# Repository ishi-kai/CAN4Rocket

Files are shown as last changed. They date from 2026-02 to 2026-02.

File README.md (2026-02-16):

# CAN Base Board for Rocket
CAN Base Board for Rocket.
The power supply section and the CAN communication section are insulated.

## Base System
This is a version with a universal board attached to the CAN base board.  
- [CAN_Isolation](./CAN_Isolation/)
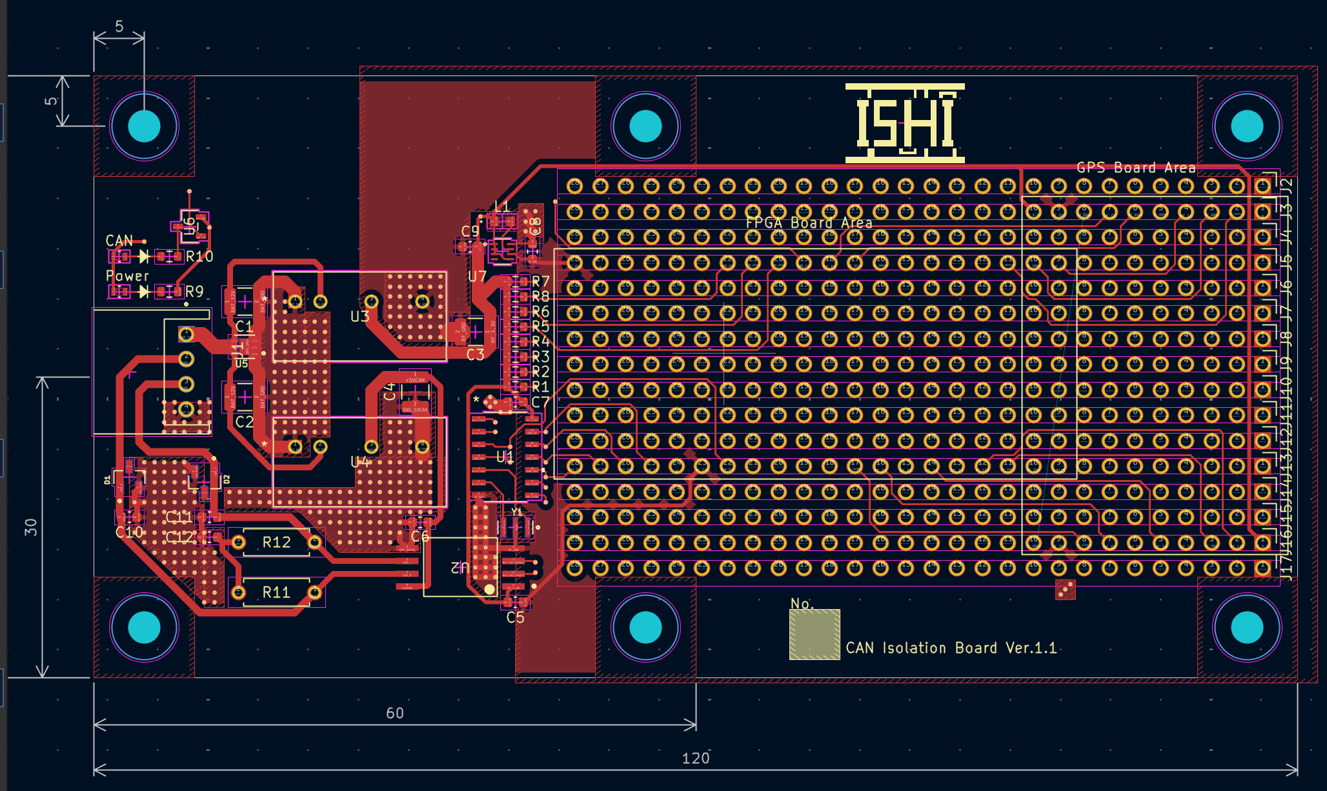
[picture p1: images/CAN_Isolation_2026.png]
CAN_Isolation
- 

## Mini System
This is a mini version of the baseboard.  

- [CAN_Isolation_mini](./CAN_Isolation_mini/)
- [CAN_Isolation_mini_3.3V](./CAN_Isolation_mini_3.3V/)
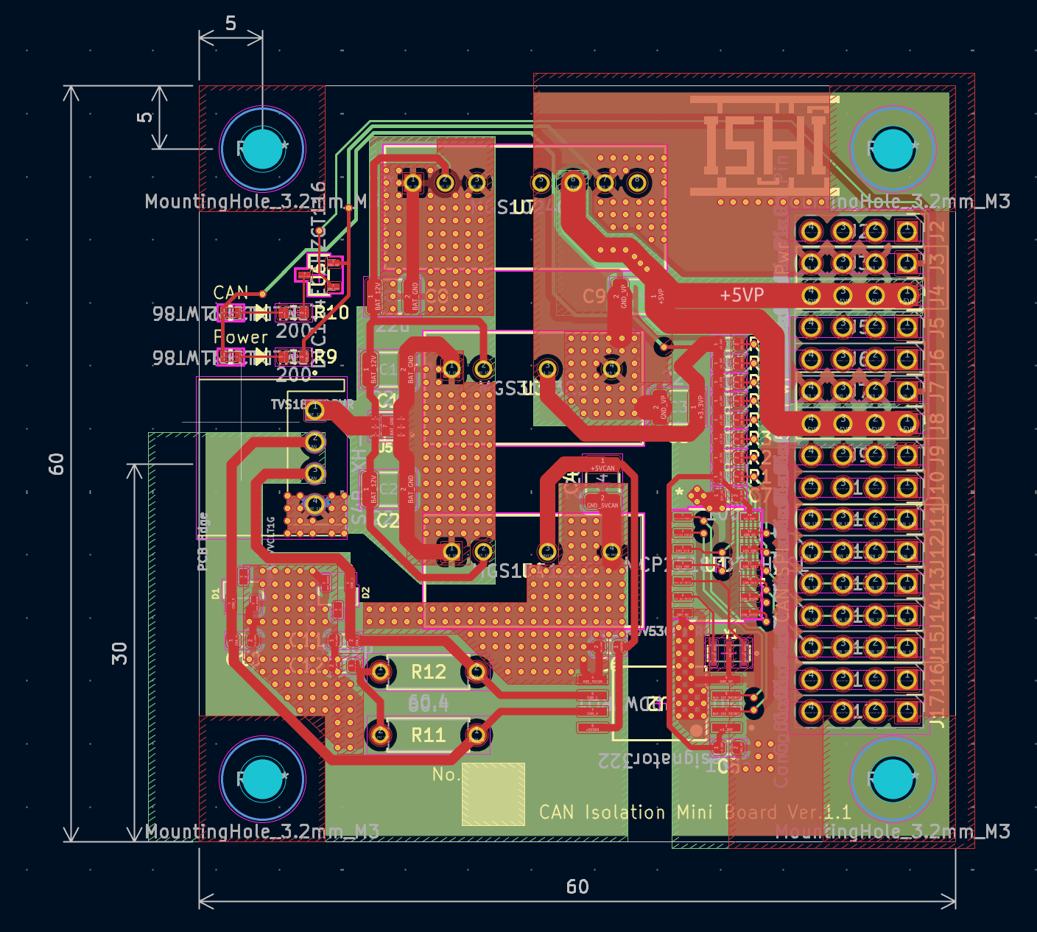
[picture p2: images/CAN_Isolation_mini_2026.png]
CAN_Isolation_mini
- 

## High-Current Board for Servos System
This is a board with an XT60 connector for servos added to the mini version.  

- [CAN_Isolation_mini_XT60](./CAN_Isolation_mini_XT60/)
- [CAN_Isolation_mini_XT60_3.3V](./CAN_Isolation_mini_XT60_3.3V/)
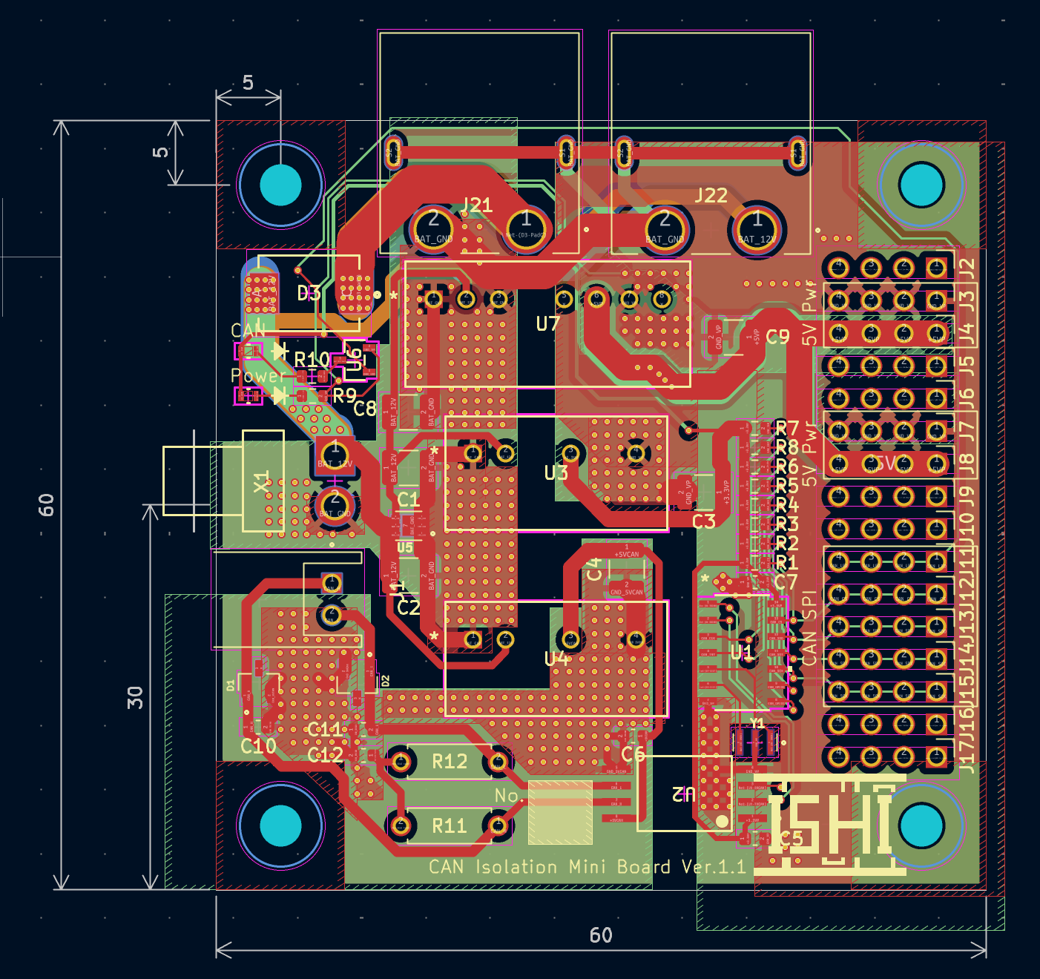
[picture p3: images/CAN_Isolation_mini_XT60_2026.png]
CAN_Isolation_mini_XT60
-

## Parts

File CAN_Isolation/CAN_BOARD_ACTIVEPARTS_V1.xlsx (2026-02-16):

出荷時に原産国が変わる場合があります。
表示されているHTSUSおよびECCN情報は情報提供のみを目的としたもので、分類の正確性や信頼性を表明または保証するものではありません。すべての情報は「現状のまま」提供されており、予告なしに変更される場合があります。提供された情報の使用は、Digi-Keyに頼ることなく、ユーザーの責任において使用されるものとします。
インデックス | メーカー品番 | メーカー名 | 商品概要 | リードタイム | 入手性 | 在庫状況 | 仕損率 | リクエスト数量1 | パック数量1 | パックタイプ1 | Digi-Key品番1 | 単価1 | 金額1 | 最小発注数量1 | 客先参照品番 | リクエスト品番 | リードタイム（週） | データシート | 参照名 | 米国輸入関税 | メモ | 部品状況 | RoHSステータス | 湿度感度レベル（MSL） | ECCN | HTSUS | 原産国 | 環境規制対応 | オリジナル品番 | 画像 | 製品に関する注意事項
1 | MCP2518FDT-H/SL | Microchip Technology | IC CAN CONTROLLER SPI 14SOIC |  | 4,201 | 在庫品目 |  | 1 | 1 | Cut Tape (CT) | MCP2518FDT-H/SLCT-ND | 2.03000 | $2.03 | 1 | 1 | MCP2518FDT-H/SLCT-ND | 6 | https://ww1.microchip.com/downloads/en/DeviceDoc/External-CAN-FD-Controller-with-SPI-Interface-DS20006027B.pdf |  | N/A |  | アクティブ | ROHS3対応 | 3（168時間） | EAR99 | 8542.39.0070 | Thailand | https://ww1.microchip.com/downloads/aemDocuments/documents/corporate-responsibilty/environmental/product-regulatory-information/Semiconductor_EnvCoC.pdf|https://ww1.microchip.com/downloads/aemDocuments/documents/corporate-responsibilty/environmental/product-regulatory-information/Microchip_REACH_Statement.pdf | MCP2518FDT-H/SLCT-ND | https://mm.digikey.com/Volume0/opasdata/d220001/medias/images/4283/150%7EC04-065%7EOD%2C-SL%7E14.jpg
2 | ISO1042QDWVRQ1 | Texas Instruments | IC TRANSCEIVER FULL 1/1 8SOIC |  | 2,190 | 在庫品目 |  | 1 | 1 | Cut Tape (CT) | 296-ISO1042QDWVRQ1CT-ND | 5.20000 | $5.20 | 1 | 1 | 296-ISO1042QDWVRQ1CT-ND | 12 | https://www.ti.com/general/docs/suppproductinfo.tsp?distId=10 |  | N/A |  | アクティブ | ROHS3対応 | 3（168時間） | EAR99 | 8542.39.0060 | Taiwan |  | 296-ISO1042QDWVRQ1CT-ND | https://mm.digikey.com/Volume0/opasdata/d220001/derivates/6/001/202/821/296%7E4218796%7EDWV%7E8_web%28640x640%29.jpg
3 | CSTNE20M0V530000R0 | Murata Electronics | CERAMIC RES 20.0000MHZ 15PF SMD |  | 15,730 | 在庫品目 |  | 1 | 1 | Cut Tape (CT) | 490-17953-1-ND | 0.22000 | $0.22 | 1 | 1 | 490-17953-1-ND | 16 | https://www.murata.com/en/products/productdata/8801161510942/SPEC-CSTNE20M0V530000R0.pdf |  | N/A |  | アクティブ | ROHS3対応 | 1（無制限） | EAR99 | 8548.00.0000 | Japan |  | 490-17953-1-ND | https://mm.digikey.com/Volume0/opasdata/d220001/medias/images/2407/CSTCR-G%20SERIES.jpg
4 | TPS610333QDRLRQ1 | Texas Instruments | IC REG BOOST 5V SOT583 |  | 2,781 | 在庫品目 |  | 1 | 1 | Cut Tape (CT) | 296-TPS610333QDRLRQ1CT-ND | 1.75000 | $1.75 | 1 | 1 | 296-TPS610333QDRLRQ1CT-ND | 12 | https://www.ti.com/lit/ds/symlink/tps610333-q1.pdf?ts=1704486161808 |  | N/A |  | アクティブ | ROHS3対応 | 1（無制限） | EAR99 | 8542.39.0090 | Philippines |  | 296-TPS610333QDRLRQ1CT-ND | https://mm.digikey.com/Volume0/opasdata/d220001/medias/images/6168/296%7E4224486%7EDRL%7E8.jpg
5 | DTC114ECAHZGT116 | Rohm Semiconductor | TRANS PREBIAS NPN 0.1A SST3 |  | 2,933 | 在庫品目 |  | 1 | 1 | Cut Tape (CT) | DTC114ECAHZGT116CT-ND | 0.17000 | $0.17 | 1 | 1 | DTC114ECAHZGT116CT-ND | 18 | https://www.rohm.co.jp/datasheet?p=DTC114ECAHZG&dist=Digi-key&media=referral&campaign=Digi-key |  | N/A |  | アクティブ | ROHS3対応 | 1（無制限） | EAR99 | 8541.21.0075 | South Korea | https://fscdn.rohm.com/en/techdata_basic/transistor/anti_whisker/TR_Whisker-e.pdf|https://fscdn.rohm.com/en/techdata_basic/transistor/esd/ESD_TR-DTC114ECAHZG-e.pdf|https://fscdn.rohm.com/en/techdata_basic/transistor/msl/TR_MSL-e.pdf | DTC114ECAHZGT116CT-ND | https://mm.digikey.com/Volume0/opasdata/d220001/medias/images/6347/846%7ESST3%7ESST%7E3.jpg
6 | MGS3123R3 | コーセル | DC DC CONVERTER 3.3V |  | 1 | 在庫品目 |  | 1 | 1 | Box | 1776-1088-ND | 14.99000 | $14.99 | 1 | 1 | 1776-1088-ND | 13 | https://en.cosel.co.jp/tool/tag/pdf/SFE_MG1R5-10.pdf |  | N/A |  | アクティブ | ROHS3対応 | 適用外 | EAR99 | 8504.40.9580 | Japan | https://en.cosel.co.jp/contact/chemical/rohs_dl/pdf/e_syoumeisyo_10.pdf | 1776-1088-ND | https://mm.digikey.com/Volume0/opasdata/d220001/medias/images/2173/MFG_MGS3.jpg
7 | MGS1R51205 | コーセル | DC DC CONVERTER 5V |  | 5 | 在庫品目 |  | 1 | 1 | Box | 1776-1077-ND | 11.43000 | $11.43 | 1 | 1 | 1776-1077-ND | 13 | https://en.cosel.co.jp/tool/tag/pdf/SFE_MG1R5-10.pdf |  | N/A |  | アクティブ | ROHS3対応 | 適用外 | EAR99 | 8504.40.9580 | Japan | https://en.cosel.co.jp/contact/chemical/rohs_dl/pdf/e_syoumeisyo_10.pdf | 1776-1077-ND | https://mm.digikey.com/Volume0/opasdata/d220001/medias/images/2320/MFG_MGS1R5.jpg
8 | MMBZ27VCLT1G | onsemi | TVS DIODE 22VWM 38VC SOT233 |  | 21,010 | 在庫品目 |  | 2 | 2 | Cut Tape (CT) | MMBZ27VCLT1GOSCT-ND | 0.12000 | $0.24 | 1 |  | MMBZ27VCLT1GOSCT-ND | 8 | https://www.onsemi.com/pdf/datasheet/mmbz15vdlt1-d.pdf |  | N/A |  | アクティブ | ROHS3対応 | 1（無制限） | EAR99 | 8541.10.0080 | China | https://www.onsemi.com/site/pdf/RoHS-statement.pdf|https://www.onsemi.com/site/pdf/REACH-compliance-statement.pdf|https://www.onsemi.com/PowerSolutions/MaterialComposition.do?export=pdf&opnId=MMBZ27VCLT1G | MMBZ27VCLT1GOSCT-ND | https://mm.digikey.com/Volume0/opasdata/d220001/medias/images/4846/488_SOT-23-3%2CTO-236-3%2CMicro3%2CSSD3%2CSST3.jpg
9 | TVS1800DRVR | Texas Instruments | UNIDIR PRECISION SURGE DIODE |  | 2,563 | 在庫品目 |  | 1 | 1 | Cut Tape (CT) | 296-52186-1-ND | 0.50000 | $0.50 | 1 |  | 296-52186-1-ND | 6 | https://www.ti.com/general/docs/suppproductinfo.tsp?distId=10 |  | N/A |  | アクティブ | ROHS3対応 | 1（無制限） | EAR99 | 8542.39.0060 | China |  | 296-52186-1-ND | https://mm.digikey.com/Volume0/opasdata/d220001/medias/images/317/296%7E4222173%7EDRV%7E6.jpg

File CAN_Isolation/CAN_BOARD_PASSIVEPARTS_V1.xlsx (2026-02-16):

出荷時に原産国が変わる場合があります。
表示されているHTSUSおよびECCN情報は情報提供のみを目的としたもので、分類の正確性や信頼性を表明または保証するものではありません。すべての情報は「現状のまま」提供されており、予告なしに変更される場合があります。提供された情報の使用は、Digi-Keyに頼ることなく、ユーザーの責任において使用されるものとします。
インデックス | メーカー品番 | メーカー名 | 商品概要 | リードタイム | 入手性 | 在庫状況 | 仕損率 | リクエスト数量1 | パック数量1 | パックタイプ1 | Digi-Key品番1 | 単価1 | 金額1 | 最小発注数量1 | 客先参照品番 | リクエスト品番 | リードタイム（週） | データシート | 参照名 | 米国輸入関税 | メモ | 部品状況 | RoHSステータス | 湿度感度レベル（MSL） | ECCN | HTSUS | 原産国 | 環境規制対応 | オリジナル品番 | 画像 | 製品に関する注意事項
1 | GCM32EC71E226KE36K | Murata Electronics | CAP CER 22UF 25V X7S 1210 |  | 30,191 | 在庫品目 |  | 4 | 4 | Cut Tape (CT) | 490-GCM32EC71E226KE36KCT-ND | 197.00000 | ¥788 | 1 | 4 | 490-GCM32EC71E226KE36KCT-ND | 14 |  |  | N/A |  | アクティブ | ROHS3対応 | 1（無制限） | EAR99 | 8532.24.0020 | Japan |  | 490-GCM32EC71E226KE36KCT-ND | https://mm.digikey.com/Volume0/opasdata/d220001/medias/images/5447/490-Ceramic-Capacitor-Tan-Field.jpg
2 | 0603YC104J4T4A | KYOCERA AVX | CAP CER 0.1UF 16V X7R 0603 |  | 19,142 | 在庫品目 |  | 3 | 3 | Cut Tape (CT) | 478-KAM15AR71C104JMCT-ND | 52.00000 | ¥156 | 1 | 5 | 478-KAM15AR71C104JMCT-ND | 12 | https://datasheets.kyocera-avx.com/AutoMLCC.pdf |  | N/A |  | アクティブ | ROHS3対応 | 1（無制限） | EAR99 | 8532.24.0020 | El Salvador |  | 478-KAM15AR71C104JMCT-ND | https://mm.digikey.com/Volume0/opasdata/d220001/medias/images/4845/478_0603-%281608-Metric%29-0%2C90mm.jpg
3 | LCCNF1608KKTR47MA | Taiyo Yuden | INDUCTOR MULTILAYER 0.47UH 0603 |  | 5,312 | 在庫品目 |  | 1 | 1 | Cut Tape (CT) | 587-LCCNF1608KKTR47MACT-ND | 69.00000 | ¥69 | 1 | 1 | 587-LCCNF1608KKTR47MACT-ND | 7 | https://mm.digikey.com/Volume0/opasdata/d220001/medias/docus/5056/LCCNF1608KKTR47MA_Spec.pdf |  | N/A |  | アクティブ | ROHS3対応 | 1（無制限） | EAR99 | 8504.50.8000 | Japan |  | 587-LCCNF1608KKTR47MACT-ND | https://mm.digikey.com/Volume0/opasdata/d220001/derivates/6/001/157/742/MFG_LCCNFxxxxKKTxxxMA_web%28640x640%29.jpg
4 | ERJ-PA3F1002V | Panasonic Electronic Components | RES SMD 10K OHM 1% 1/3W 0603 |  | 90,888 | 在庫品目 |  | 8 | 8 | Cut Tape (CT) | P10KBYCT-ND | 22.00000 | ¥176 | 1 | 8 | P10KBYCT-ND | 12 | https://industrial.panasonic.com/cdbs/www-data/pdf/RDO0000/AOA0000C331.pdf |  | N/A |  | アクティブ | ROHS3対応 | 1（無制限） | EAR99 | 8533.21.0030 | Japan | https://industrial.panasonic.com/cdbs/www-cgi/auto-publishing.cgi?type=ROSU&region=WW&layer=4&cd=AOA0002 | P10KBYCT-ND | https://mm.digikey.com/Volume0/opasdata/d220001/medias/images/4322/cut-tape-render.jpg
5 | ERJ-3GEYJ201V | Panasonic Electronic Components | RES SMD 200 OHM 5% 1/10W 0603 |  | 394,282 | 在庫品目 |  | 2 | 2 | Cut Tape (CT) | P200GCT-ND | 16.00000 | ¥32 | 1 | 2 | P200GCT-ND | 12 | https://industrial.panasonic.com/cdbs/www-data/pdf/RDA0000/AOA0000C301.pdf |  | N/A |  | アクティブ | ROHS3対応 | 1（無制限） | EAR99 | 8533.21.0030 | China | https://industrial.panasonic.com/cdbs/www-cgi/auto-publishing.cgi?type=ROSU&region=WW&layer=4&cd=AOA0002 | P200GCT-ND | https://mm.digikey.com/Volume0/opasdata/d220001/medias/images/2606/MFG_ERJ-P6W%20Series.jpg
6 | SMLD12EN1WT86C | Rohm Semiconductor | LONG LIFE TYPE MINI-MOLD CHIP LE |  | 548 | 在庫品目 |  | 2 | 2 | Cut Tape (CT) | 846-SMLD12EN1WT86CCT-ND | 88.00000 | ¥176 | 1 | 2 | 846-SMLD12EN1WT86CCT-ND | 10 | https://www.rohm.com/datasheet?p=SMLD12EN1W(C)&dist=Digi-Key&media=referral&campaign=Digi-Key |  | N/A |  | アクティブ | ROHS3対応 | 3（168時間） | EAR99 | 8541.41.0000 | China |  | 846-SMLD12EN1WT86CCT-ND | https://mm.digikey.com/Volume0/opasdata/d220001/medias/images/5739/MFG_SMLD12EN1WT86C.jpg
7 | CHV0603N250470GCT | Cal-Chip Electronics, Inc. | HVCAP0603 COG 47PF 2% 250V |  | 2,968 | 在庫品目 |  | 2 | 2 | Cut Tape (CT) | 4713-CHV0603N250470GCT-ND | 84.00000 | ¥168 | 1 |  | 4713-CHV0603N250470GCT-ND | 8 | https://calchip.com/wp-content/uploads/2023/02/chv_series.pdf |  | N/A |  | アクティブ | ROHS3対応 | 1（無制限） | EAR99 | 8532.24.0020 | South Korea |  | 4713-CHV0603N250470GCT-ND | https://mm.digikey.com/Volume0/opasdata/d220001/derivates/6/003/164/759/MFG_Cal-Chip-All-Capacitors_web%28640x640%29.jpg
8 | 06031C472K4T2A | KYOCERA AVX | CAP CER 4700PF 100V X7R 0603 |  | 117,434 | 在庫品目 |  | 1 | 1 | Cut Tape (CT) | 478-KAM15AR72A472KTCT-ND | 16.00000 | ¥16 | 1 |  | 478-KAM15AR72A472KTCT-ND | 12 | https://datasheets.kyocera-avx.com/AutoMLCC.pdf |  | N/A |  | アクティブ | ROHS3対応 | 1（無制限） | EAR99 | 8532.24.0020 | El Salvador |  | 478-KAM15AR72A472KTCT-ND | https://mm.digikey.com/Volume0/opasdata/d220001/medias/images/4845/478_0603-%281608-Metric%29-0%2C90mm.jpg
9 | MF1/4DCT52R60R4F | KOA Speer Electronics, Inc. | RES 60.4 OHM 1% 1/4W AXIAL |  | 4,718 | 在庫品目 |  | 2 | 2 | Cut Tape (CT) | 2019-MF1/4DCT52R60R4FCT-ND | 16.00000 | ¥32 | 1 |  | 2019-MF1/4DCT52R60R4FCT-ND | 17 | https://www.koaspeer.com/pdfs/MF-MFS-RK.pdf |  | N/A |  | アクティブ | ROHS3対応 | 適用外 | EAR99 | 8533.21.0090 | Taiwan | https://www.koaglobal.com/product/common/rohs|https://mm.digikey.com/Volume0/opasdata/d220001/medias/docus/5718/2019_KOA%20Speer%20RoHS3%20Statement.pdf | 2019-MF1/4DCT52R60R4FCT-ND | https://mm.digikey.com/Volume0/opasdata/d220001/medias/images/5374/GP_series.jpg
10 | GRT188C80J226ME13D | Murata Electronics | CAP CER 22UF 6.3V X6S 0603 |  | 106,128 | 在庫品目 |  | 2 | 2 | Cut Tape (CT) | 490-GRT188C80J226ME13DCT-ND | 58.00000 | ¥116 | 1 |  | 490-GRT188C80J226ME13DCT-ND | 16 | https://search.murata.co.jp/Ceramy/image/img/A01X/G101/ENG/GRT188C80J226ME13-01.pdf |  | N/A |  | アクティブ | ROHS3対応 | 1（無制限） | EAR99 | 8532.24.0020 | Japan |  | 490-GRT188C80J226ME13DCT-ND | https://mm.digikey.com/Volume0/opasdata/d220001/medias/images/5447/490-Ceramic-Capacitor-Tan-Field.jpg

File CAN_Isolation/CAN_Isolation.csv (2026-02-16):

Reference | Qty | Value | DNP | Exclude from BOM | Exclude from Board | Footprint | Datasheet
C1,C2,C3,C4 | 4 | 22u |  |  |  | Capacitor_SMD:C_1210_3225Metric | ~
C5,C6,C7 | 3 | 100n |  |  |  | Capacitor_SMD:C_0603_1608Metric | ~
C8,C9 | 2 | 22u |  |  |  | Capacitor_SMD:C_0603_1608Metric | ~
C10,C11 | 2 | 47p |  |  |  | Capacitor_SMD:C_0603_1608Metric | ~
C12 | 1 | 4700p |  |  |  | Capacitor_SMD:C_0603_1608Metric | ~
D1,D2 | 2 | MMBZ27VCLT1G |  |  |  | CAN_Isolation:SOT95P237X111-3N
J1 | 1 | S4B-XH-A |  |  |  | CAN_Isolation:JST_S4B-XH-A
J2,J3,J4,J5,J6,J7,J8,J9,J10,J11,J12,J13,J14,J15,J16,J17 | 16 | Conn_01x28 |  |  |  | CAN_Isolation:PinHeader_1x28_P2.54mm_NoSilkScreen | ~
L1 | 1 | 0.47uH |  |  |  | CAN_Isolation:IND_LCCN_1608KK_TAY | ~
LED1,LED2 | 2 | SMLD12EN1WT86 |  |  |  | CAN_Isolation:SMLD12EN1WT86 | SMLD12EN1WT86
R1,R2,R3,R4,R5,R6,R7,R8 | 8 | 10k |  |  |  | Resistor_SMD:R_0603_1608Metric | ~
R9,R10 | 2 | 200 |  |  |  | Resistor_SMD:R_0603_1608Metric | ~
R11,R12 | 2 | 60.4 |  |  |  | Resistor_THT:R_Axial_DIN0207_L6.3mm_D2.5mm_P7.62mm_Horizontal | ~
U1 | 1 | MCP2518FDT-H/SL |  |  |  | CAN_Isolation:SOIC14_150MIL_SL_MCH | MCP2518FDT-H/SL
U2 | 1 | ISO1042QDWVRQ1 |  |  |  | CAN_Isolation:DWV0008A-IPC_A | https://www.ti.com/lit/gpn/iso1042-q1
U3 | 1 | MGS3123R3 |  |  |  | CAN_Isolation:MGS3_COS | MGS3123R3
U4 | 1 | MGS1R51205 |  |  |  | CAN_Isolation:MGS3_COS | MGS3123R3
U5 | 1 | TVS1800DRVR |  |  |  | CAN_Isolation:SON65P200X200X80-7N
U6 | 1 | DTC114ECAHZGT116 |  |  |  | CAN_Isolation:TRANS_DTCZCAHZGT_ROM | DTC114ECAHZGT116
U7 | 1 | TPS610333QDRLRQ1 |  |  |  | CAN_Isolation:SOT-5X3-8_DRL_TEX | https://www.ti.com/lit/gpn/tps610333-q1
Y1 | 1 | CSTNE20M0V530000R0 |  |  |  | CAN_Isolation:OSC_CSTNE20M0V530000R0

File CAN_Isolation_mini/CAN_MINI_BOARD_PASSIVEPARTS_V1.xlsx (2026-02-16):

出荷時に原産国が変わる場合があります。
表示されているHTSUSおよびECCN情報は情報提供のみを目的としたもので、分類の正確性や信頼性を表明または保証するものではありません。すべての情報は「現状のまま」提供されており、予告なしに変更される場合があります。提供された情報の使用は、Digi-Keyに頼ることなく、ユーザーの責任において使用されるものとします。
インデックス | メーカー品番 | メーカー名 | 商品概要 | リードタイム | 入手性 | 在庫状況 | 仕損率 | リクエスト数量1 | パック数量1 | パックタイプ1 | Digi-Key品番1 | 単価1 | 金額1 | 最小発注数量1 | 客先参照品番 | リクエスト品番 | リードタイム（週） | データシート | 参照名 | 米国輸入関税 | メモ | 部品状況 | RoHSステータス | 湿度感度レベル（MSL） | ECCN | HTSUS | 原産国 | 環境規制対応 | オリジナル品番 | 画像 | 製品に関する注意事項
1 | GCM32EC71E226KE36K | Murata Electronics | CAP CER 22UF 25V X7S 1210 |  | 6,775 | 在庫品目 |  | 6 | 6 | Cut Tape (CT) | 490-GCM32EC71E226KE36KCT-ND | 1.25000 | $7.50 | 1 | 4 | 490-GCM32EC71E226KE36KCT-ND | 14 | https://search.murata.co.jp/Ceramy/image/img/A01X/G101/ENG/GCJ188R71H104KA12-02B.pdf |  | N/A |  | アクティブ | ROHS3対応 | 1（無制限） | EAR99 | 8532.24.0020 | Japan |  | 490-GCM32EC71E226KE36KCT-ND | https://mm.digikey.com/Volume0/opasdata/d220001/medias/images/5447/490-Ceramic-Capacitor-Tan-Field.jpg
2 | 0603YC104J4T4A | KYOCERA AVX | CAP CER 0.1UF 16V X7R 0603 |  | 5,180 | 在庫品目 |  | 3 | 3 | Cut Tape (CT) | 478-KAM15AR71C104JMCT-ND | 0.33000 | $0.99 | 1 | 5 | 478-KAM15AR71C104JMCT-ND | 12 | https://datasheets.kyocera-avx.com/AutoMLCC.pdf |  | N/A |  | アクティブ | ROHS3対応 | 1（無制限） | EAR99 | 8532.24.0020 | El Salvador |  | 478-KAM15AR71C104JMCT-ND | https://mm.digikey.com/Volume0/opasdata/d220001/medias/images/4845/478_0603-%281608-Metric%29-0%2C90mm.jpg
3 | ERJ-PA3F1002V | Panasonic Electronic Components | RES SMD 10K OHM 1% 1/3W 0603 |  | 52,034 | 在庫品目 |  | 8 | 8 | Cut Tape (CT) | P10KBYCT-ND | 0.14000 | $1.12 | 1 | 8 | P10KBYCT-ND | 12 | https://industrial.panasonic.com/cdbs/www-data/pdf/RDO0000/AOA0000C331.pdf |  | N/A |  | アクティブ | ROHS3対応 | 1（無制限） | EAR99 | 8533.21.0030 | Japan | https://industrial.panasonic.com/cdbs/www-cgi/auto-publishing.cgi?type=ROSU&region=WW&layer=4&cd=AOA0002 | P10KBYCT-ND | https://mm.digikey.com/Volume0/opasdata/d220001/medias/images/4322/cut-tape-render.jpg
4 | ERJ-3GEYJ201V | Panasonic Electronic Components | RES SMD 200 OHM 5% 1/10W 0603 |  | 459,412 | 在庫品目 |  | 2 | 2 | Cut Tape (CT) | P200GCT-ND | 0.10000 | $0.20 | 1 | 2 | P200GCT-ND | 12 | https://industrial.panasonic.com/ww/products/pt/general-purpose-chip-resistors/models/ERJ3GEYJ201V |  | N/A |  | アクティブ | ROHS3対応 | 1（無制限） | EAR99 | 8533.21.0030 | China | https://industrial.panasonic.com/cdbs/www-cgi/auto-publishing.cgi?type=ROSU&region=WW&layer=4&cd=AOA0002 | P200GCT-ND | https://mm.digikey.com/Volume0/opasdata/d220001/medias/images/2606/MFG_ERJ-P6W%20Series.jpg
5 | SMLD12EN1WT86C | Rohm Semiconductor | LONG LIFE TYPE MINI-MOLD CHIP LE |  | 1,099 | 在庫品目 |  | 2 | 2 | Cut Tape (CT) | 846-SMLD12EN1WT86CCT-ND | 0.56000 | $1.12 | 1 | 2 | 846-SMLD12EN1WT86CCT-ND | 10 | https://www.rohm.com/datasheet?p=SMLD12EN1W(C)&dist=Digi-Key&media=referral&campaign=Digi-Key |  | N/A |  | アクティブ | ROHS3対応 | 3（168時間） | EAR99 | 8541.41.0000 | China |  | 846-SMLD12EN1WT86CCT-ND | https://mm.digikey.com/Volume0/opasdata/d220001/medias/images/5739/MFG_SMLD12EN1WT86C.jpg
6 | CHV0603N250470GCT | Cal-Chip Electronics, Inc. | HVCAP0603 COG 47PF 2% 250V |  | 3,020 | 在庫品目 |  | 2 | 2 | Cut Tape (CT) | 4713-CHV0603N250470GCT-ND | 0.59000 | $1.18 | 1 |  | 4713-CHV0603N250470GCT-ND | 8 | https://calchip.com/wp-content/uploads/2023/02/chv_series.pdf |  | N/A |  | アクティブ | ROHS3対応 | 1（無制限） | EAR99 | 8532.24.0020 | South Korea |  | 4713-CHV0603N250470GCT-ND | https://mm.digikey.com/Volume0/opasdata/d220001/derivates/6/003/164/759/MFG_Cal-Chip-All-Capacitors_web%28640x640%29.jpg
7 | 06031C472K4T2A | KYOCERA AVX | CAP CER 4700PF 100V X7R 0603 |  | 118,500 | 在庫品目 |  | 1 | 1 | Cut Tape (CT) | 478-KAM15AR72A472KTCT-ND | 0.10000 | $0.10 | 1 |  | 478-KAM15AR72A472KTCT-ND | 12 | https://datasheets.kyocera-avx.com/AutoMLCC.pdf |  | N/A |  | アクティブ | ROHS3対応 | 1（無制限） | EAR99 | 8532.24.0020 | El Salvador |  | 478-KAM15AR72A472KTCT-ND | https://mm.digikey.com/Volume0/opasdata/d220001/medias/images/4845/478_0603-%281608-Metric%29-0%2C90mm.jpg
8 | MF1/4DCT52R60R4F | KOA Speer Electronics, Inc. | RES 60.4 OHM 1% 1/4W AXIAL |  | 4,750 | 在庫品目 |  | 2 | 2 | Cut Tape (CT) | 2019-MF1/4DCT52R60R4FCT-ND | 0.10000 | $0.20 | 1 |  | 2019-MF1/4DCT52R60R4FCT-ND | 17 | https://www.koaspeer.com/pdfs/MF-MFS-RK.pdf |  | N/A |  | アクティブ | ROHS3対応 | 適用外 | EAR99 | 8533.21.0090 | Taiwan | https://www.koaglobal.com/-/media/Files/KOA_Global/product/common/rohs/Certificate_of_RoHS_Compliance_July2024.pdf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|https://mm.digikey.com/Volume0/opasdata/d220001/medias/docus/5718/2019_KOA%20Speer%20RoHS3%20Statement.pdf | 2019-MF1/4DCT52R60R4FCT-ND | https://mm.digikey.com/Volume0/opasdata/d220001/medias/images/5374/GP_series.jpg

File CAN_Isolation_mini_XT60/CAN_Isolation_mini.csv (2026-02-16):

Reference | Qty | Value | DNP | Exclude from BOM | Exclude from Board | Footprint | Datasheet
C1,C2,C3,C4,C8,C9 | 6 | 22u |  |  |  | Capacitor_SMD:C_1210_3225Metric | ~
C5,C6,C7 | 3 | 100n |  |  |  | Capacitor_SMD:C_0603_1608Metric | ~
C10,C11 | 2 | 47p |  |  |  | Capacitor_SMD:C_0603_1608Metric | ~
C12 | 1 | 4700p |  |  |  | Capacitor_SMD:C_0603_1608Metric | ~
D1,D2 | 2 | MMBZ27VCLT1G |  |  |  | CAN_Isolation:SOT95P237X111-3N
D3 | 1 | B520CQ-13-F |  |  |  | CAN_Isolation:DIOM7959X250N
J1,J18,J19 | 3 | S2B-XH-A |  |  |  | CAN_Isolation:JST_S2B-XH-A
J2,J3,J4,J5,J6,J7,J8,J9,J10,J11,J12,J13,J14,J15,J16,J17 | 16 | Conn_01x04_Pin |  |  |  | CAN_Isolation:PinHeader_1x04_P2.54mm_Vertical_noSilk | ~
J20 | 1 | S5B-XH-A |  |  |  | CAN_Isolation:JST_S5B-XH-A
J21,J22 | 2 | XT60PW-F |  |  |  | CAN_Isolation:AMASS_XT60PW-F
LED1,LED2 | 2 | SMLD12EN1WT86 |  |  |  | CAN_Isolation:SMLD12EN1WT86 | SMLD12EN1WT86
R1,R2,R3,R4,R5,R6,R7,R8 | 8 | 10k |  |  |  | Resistor_SMD:R_0603_1608Metric | ~
R9,R10 | 2 | 200 |  |  |  | Resistor_SMD:R_0603_1608Metric | ~
R11,R12 | 2 | 60.4 |  |  |  | Resistor_THT:R_Axial_DIN0207_L6.3mm_D2.5mm_P7.62mm_Horizontal | ~
U1 | 1 | MCP2518FDT-H/SL |  |  |  | CAN_Isolation:SOIC14_150MIL_SL_MCH | MCP2518FDT-H/SL
U2 | 1 | ISO1042QDWVRQ1 |  |  |  | CAN_Isolation:DWV0008A-IPC_A | https://www.ti.com/lit/gpn/iso1042-q1
U3 | 1 | MGS3123R3 |  |  |  | CAN_Isolation:MGS3_COS | MGS3123R3
U4 | 1 | MGS1R51205 |  |  |  | CAN_Isolation:MGS3_COS | MGS3123R3
U5 | 1 | TVS1800DRVR |  |  |  | CAN_Isolation:SON65P200X200X80-7N
U6 | 1 | DTC114ECAHZGT116 |  |  |  | CAN_Isolation:TRANS_DTCZCAHZGT_ROM | DTC114ECAHZGT116
U7 | 1 | MGS102405 |  |  |  | CAN_Isolation:SIP7_MGS10_COS | MGS102405
X1 | 1 | B2PS-VH |  |  |  | CAN_Isolation:B2PS-VH
Y1 | 1 | CSTNE20M0V530000R0 |  |  |  | CAN_Isolation:OSC_CSTNE20M0V530000R0

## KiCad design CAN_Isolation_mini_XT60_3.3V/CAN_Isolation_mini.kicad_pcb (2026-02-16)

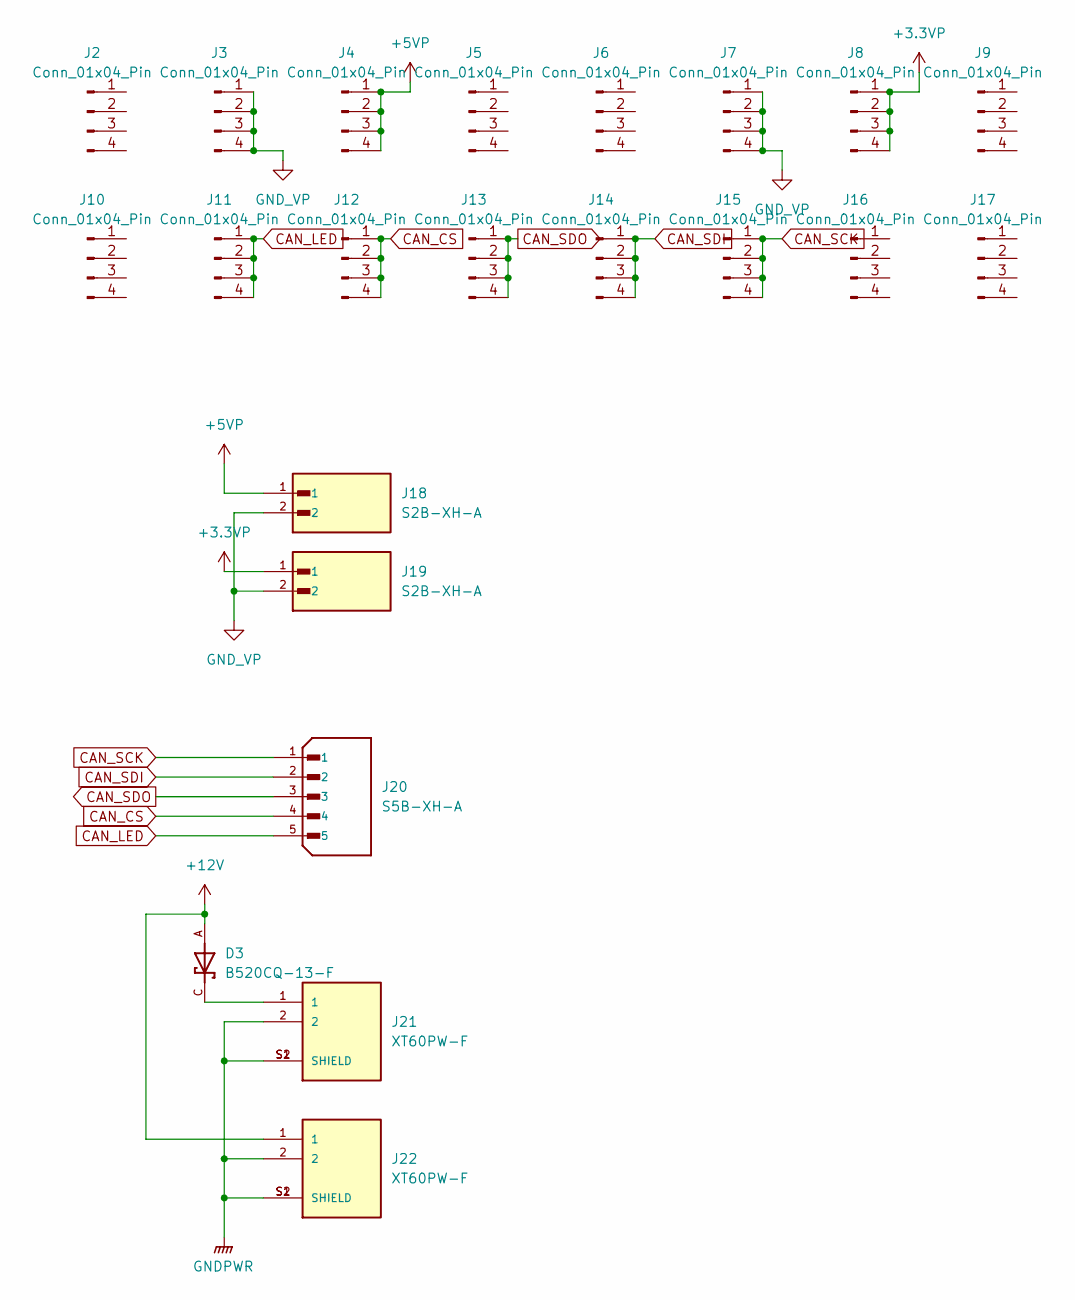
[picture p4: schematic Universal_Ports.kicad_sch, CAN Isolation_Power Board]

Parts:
D3: B520CQ-13-F; DIOM7959X250N
J2, J3, J4, J5, J6, J7, J8, J9, J10, J11, J12, J13, J14, J15, J16, J17: Conn_01x04_Pin; PinHeader_1x04_P2.54mm_Vertical_noSilk
J18, J19: S2B-XH-A; JST_S2B-XH-A
J20: S5B-XH-A; JST_S5B-XH-A; PARTREV 27-1-20
J21, J22: XT60PW-F; AMASS_XT60PW-F; PARTREV V1.2

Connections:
+3.3VP: J8.1, J8.2, J8.3, J8.4, J19.1; also elsewhere on the board
+5VP: J4.1, J4.2, J4.3, J4.4, J18.1; also elsewhere on the board
BAT_12V: D3.A, J22.1; also elsewhere on the board
BAT_GND: J21.2, J21.S1 (SHIELD), J21.S2 (SHIELD), J22.2, J22.S1 (SHIELD), J22.S2 (SHIELD); also elsewhere on the board
CAN_CS: J12.1, J12.2, J12.3, J12.4, J20.4; also elsewhere on the board
CAN_LED: J11.1, J11.2, J11.3, J11.4, J20.5; also elsewhere on the board
CAN_SCK: J15.1, J15.2, J15.3, J15.4, J20.1; also elsewhere on the board
CAN_SDI: J14.1, J14.2, J14.3, J14.4, J20.2; also elsewhere on the board
CAN_SDO: J13.1, J13.2, J13.3, J13.4, J20.3; also elsewhere on the board
GND_VP: J3.1, J3.2, J3.3, J3.4, J7.1, J7.2, J7.3, J7.4, J18.2, J19.2; also elsewhere on the board
unnamed: D3.C, J21.1

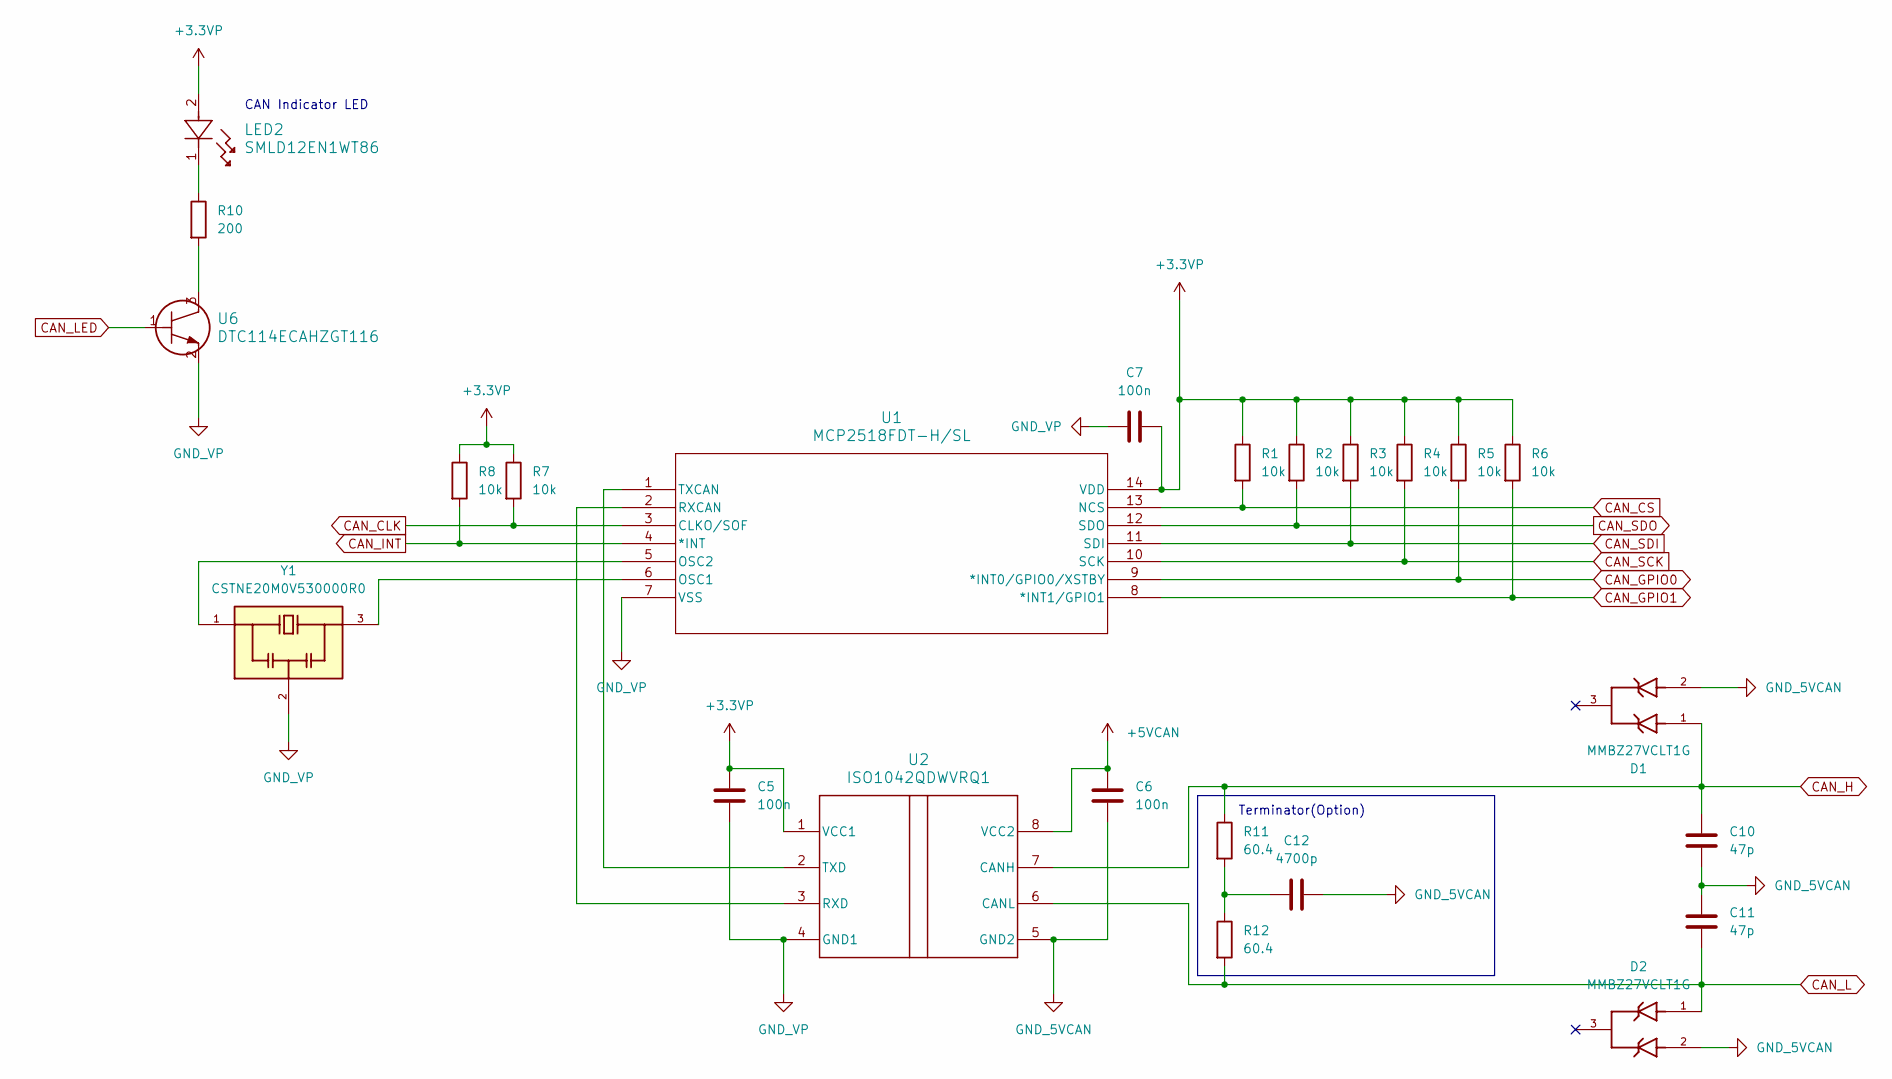
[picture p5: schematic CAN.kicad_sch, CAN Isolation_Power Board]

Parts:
C5, C6, C7: 100n; C_0603_1608Metric
C10, C11: 47p; C_0603_1608Metric
C12: 4700p; C_0603_1608Metric
D1, D2: MMBZ27VCLT1G; SOT95P237X111-3N; PARTREV 17
LED2: SMLD12EN1WT86
R1, R2, R3, R4, R5, R6, R7, R8: 10k; R_0603_1608Metric
R10: 200; R_0603_1608Metric
R11, R12: 60.4; R_Axial_DIN0207_L6.3mm_D2.5mm_P7.62mm_Horizontal
U1: MCP2518FDT-H/SL; SOIC14_150MIL_SL_MCH
U2: ISO1042QDWVRQ1; DWV0008A-IPC_A
U6: DTC114ECAHZGT116; TRANS_DTCZCAHZGT_ROM
Y1: CSTNE20M0V530000R0; OSC_CSTNE20M0V530000R0; PARTREV JGC42-8853B

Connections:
+3.3VP: C5.1, C7.2, LED2.2, R1.1, R2.1, R3.1, R4.1, R5.1, R6.1, R7.1, R8.1, U1.14 (VDD), U2.1 (VCC1); also elsewhere on the board
+5VCAN: C6.1, U2.8 (VCC2); also elsewhere on the board
CAN_CLK: R7.2, U1.3 (CLKO/SOF)
CAN_CS: R1.2, U1.13 (NCS); also elsewhere on the board
CAN_GPIO0: R5.2, U1.9 (*INT0/GPIO0/XSTBY)
CAN_GPIO1: R6.2, U1.8 (*INT1/GPIO1)
CAN_H: C10.1, D1.1, R11.1, U2.7 (CANH); also elsewhere on the board
CAN_INT: R8.2, U1.4 (*INT)
CAN_L: C11.2, D2.1, R12.2, U2.6 (CANL); also elsewhere on the board
CAN_LED: U6.1; also elsewhere on the board
CAN_SCK: R4.2, U1.10 (SCK); also elsewhere on the board
CAN_SDI: R3.2, U1.11 (SDI); also elsewhere on the board
CAN_SDO: R2.2, U1.12 (SDO); also elsewhere on the board
GND_5VCAN: C6.2, C10.2, C11.1, C12.2, D1.2, D2.2, U2.5 (GND2); also elsewhere on the board
GND_VP: C5.2, C7.1, U1.7 (VSS), U2.4 (GND1), U6.2, Y1.2; also elsewhere on the board
unnamed: C12.1, R11.2, R12.1
unnamed: LED2.1, R10.1
unnamed: R10.2, U6.3
unnamed: U1.6 (OSC1), Y1.3
unnamed: U1.5 (OSC2), Y1.1
unnamed: U1.2 (RXCAN), U2.3 (RXD)
unnamed: U1.1 (TXCAN), U2.2 (TXD)

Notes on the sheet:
CAN Indicator LED
Terminator(Option)

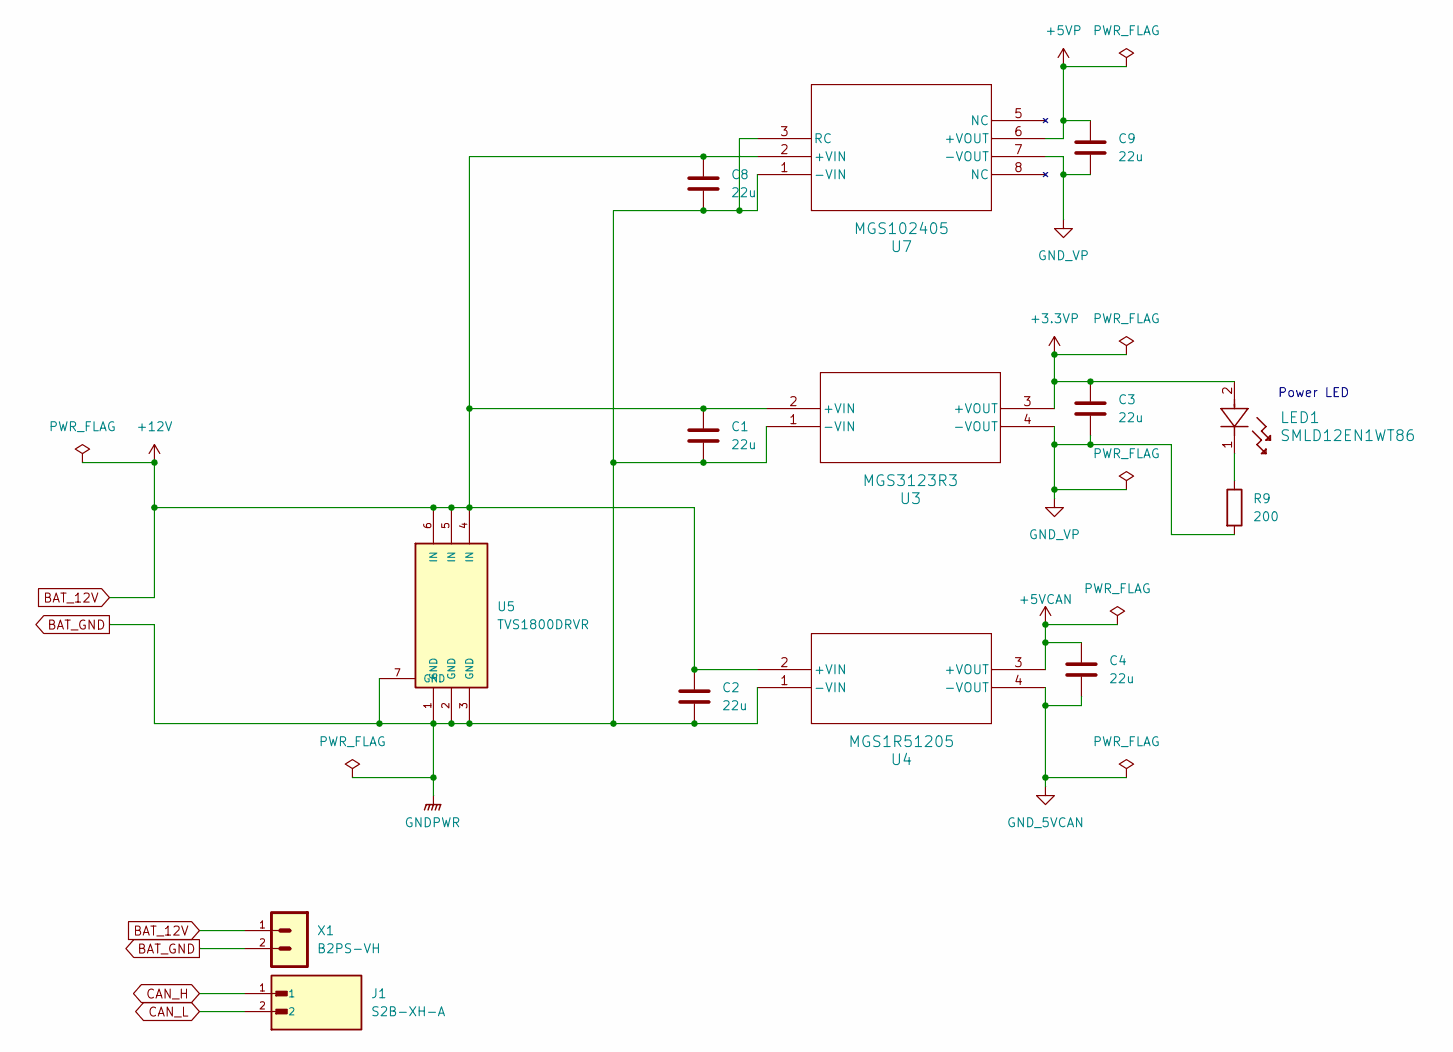
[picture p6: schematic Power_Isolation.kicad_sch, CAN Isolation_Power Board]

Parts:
C1, C2, C3, C4, C8, C9: 22u; C_1210_3225Metric
J1: S2B-XH-A; JST_S2B-XH-A
LED1: SMLD12EN1WT86
R9: 200; R_0603_1608Metric
U3: MGS3123R3; MGS3_COS
U4: MGS1R51205; MGS3_COS
U5: TVS1800DRVR; SON65P200X200X80-7N; PARTREV C
U7: MGS102405; SIP7_MGS10_COS
X1: B2PS-VH

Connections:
+3.3VP: C3.1, LED1.2, U3.3 (+VOUT); also elsewhere on the board
+5VCAN: C4.1, U4.3 (+VOUT); also elsewhere on the board
+5VP: C9.1, U7.6 (+VOUT); also elsewhere on the board
BAT_12V: C1.1, C2.1, C8.1, U3.2 (+VIN), U4.2 (+VIN), U5.4 (IN), U5.5 (IN), U5.6 (IN), U7.2 (+VIN), X1.1; also elsewhere on the board
BAT_GND: C1.2, C2.2, C8.2, U3.1 (-VIN), U4.1 (-VIN), U5.1 (GND), U5.2 (GND), U5.3 (GND), U5.7 (GND), U7.1 (-VIN), U7.3 (RC), X1.2; also elsewhere on the board
CAN_H: J1.1; also elsewhere on the board
CAN_L: J1.2; also elsewhere on the board
GND_5VCAN: C4.2, U4.4 (-VOUT); also elsewhere on the board
GND_VP: C3.2, C9.2, R9.2, U3.4 (-VOUT), U7.7 (-VOUT); also elsewhere on the board
unnamed: LED1.1, R9.1

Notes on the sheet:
Power LED

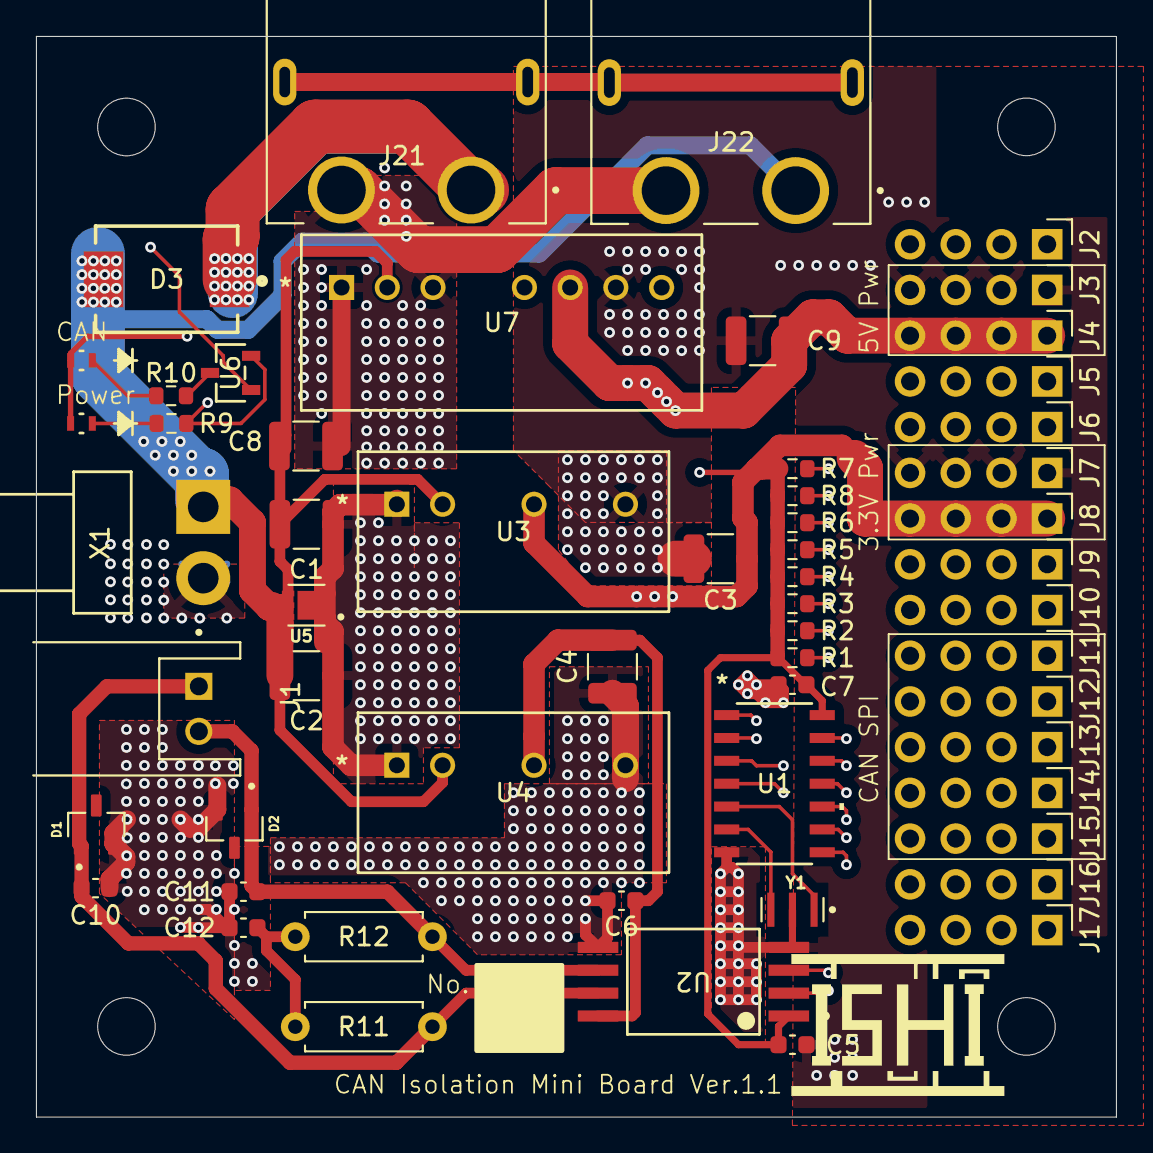
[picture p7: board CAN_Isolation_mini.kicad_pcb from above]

Board: 4 copper layers, 60.0 x 60.0 mm, 57 parts (0 on the bottom side), 27 nets.

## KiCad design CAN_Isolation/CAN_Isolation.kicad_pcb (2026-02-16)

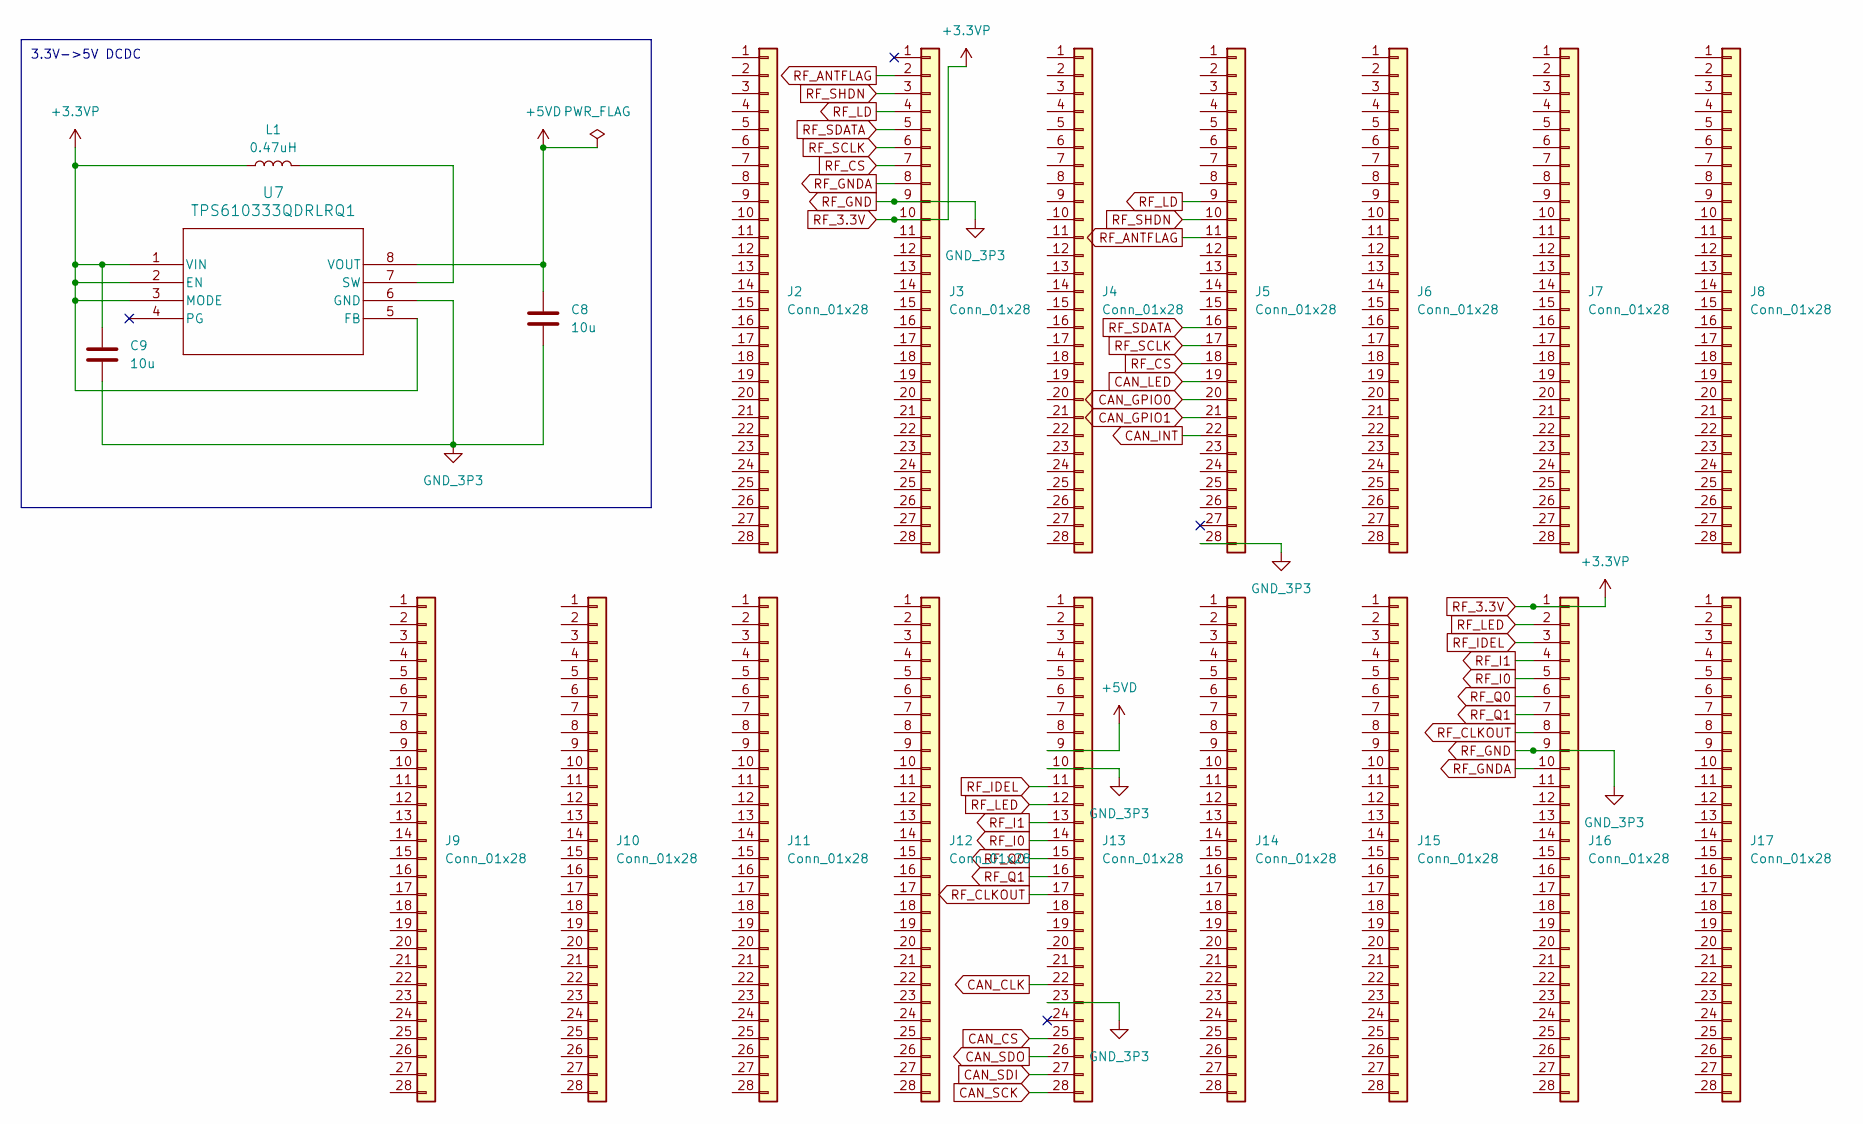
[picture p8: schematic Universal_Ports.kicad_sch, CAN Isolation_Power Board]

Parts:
C8, C9: 10u; C_0603_1608Metric
J2, J3, J4, J5, J6, J7, J8, J9, J10, J11, J12, J13, J14, J15, J16, J17: Conn_01x28; PinHeader_1x28_P2.54mm_NoSilkScreen
L1: 0.47uH; IND_LCCN_1608KK_TAY
U7: TPS610333QDRLRQ1; SOT-5X3-8_DRL_TEX

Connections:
+5VD: C8.1, J13.9, U7.8 (VOUT)
CAN_CLK: J13.22; also elsewhere on the board
CAN_CS: J13.25; also elsewhere on the board
CAN_GPIO0: J5.20; also elsewhere on the board
CAN_GPIO1: J5.21; also elsewhere on the board
CAN_INT: J5.22; also elsewhere on the board
CAN_LED: J5.19; also elsewhere on the board
CAN_SCK: J13.28; also elsewhere on the board
CAN_SDI: J13.27; also elsewhere on the board
CAN_SDO: J13.26; also elsewhere on the board
unnamed: L1.2, U7.7 (SW)
RF_3.3V: C9.1, J3.10, J16.1, L1.1, U7.1 (VIN), U7.2 (EN), U7.3 (MODE), U7.5 (FB); also elsewhere on the board
RF_ANTFLAG: J3.2, J5.11
RF_CLKOUT: J13.17, J16.8
RF_CS: J3.7, J5.18
RF_GND: C8.2, C9.2, J3.9, J5.28, J13.10, J13.23, J16.9, U7.6 (GND); also elsewhere on the board
RF_GNDA: J3.8, J16.10
RF_I0: J13.14, J16.5
RF_I1: J13.13, J16.4
RF_IDEL: J13.11, J16.3
RF_LD: J3.4, J5.9
RF_LED: J13.12, J16.2
RF_Q0: J13.15, J16.6
RF_Q1: J13.16, J16.7
RF_SCLK: J3.6, J5.17
RF_SDATA: J3.5, J5.16
RF_SHDN: J3.3, J5.10

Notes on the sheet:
3.3V->5V DCDC

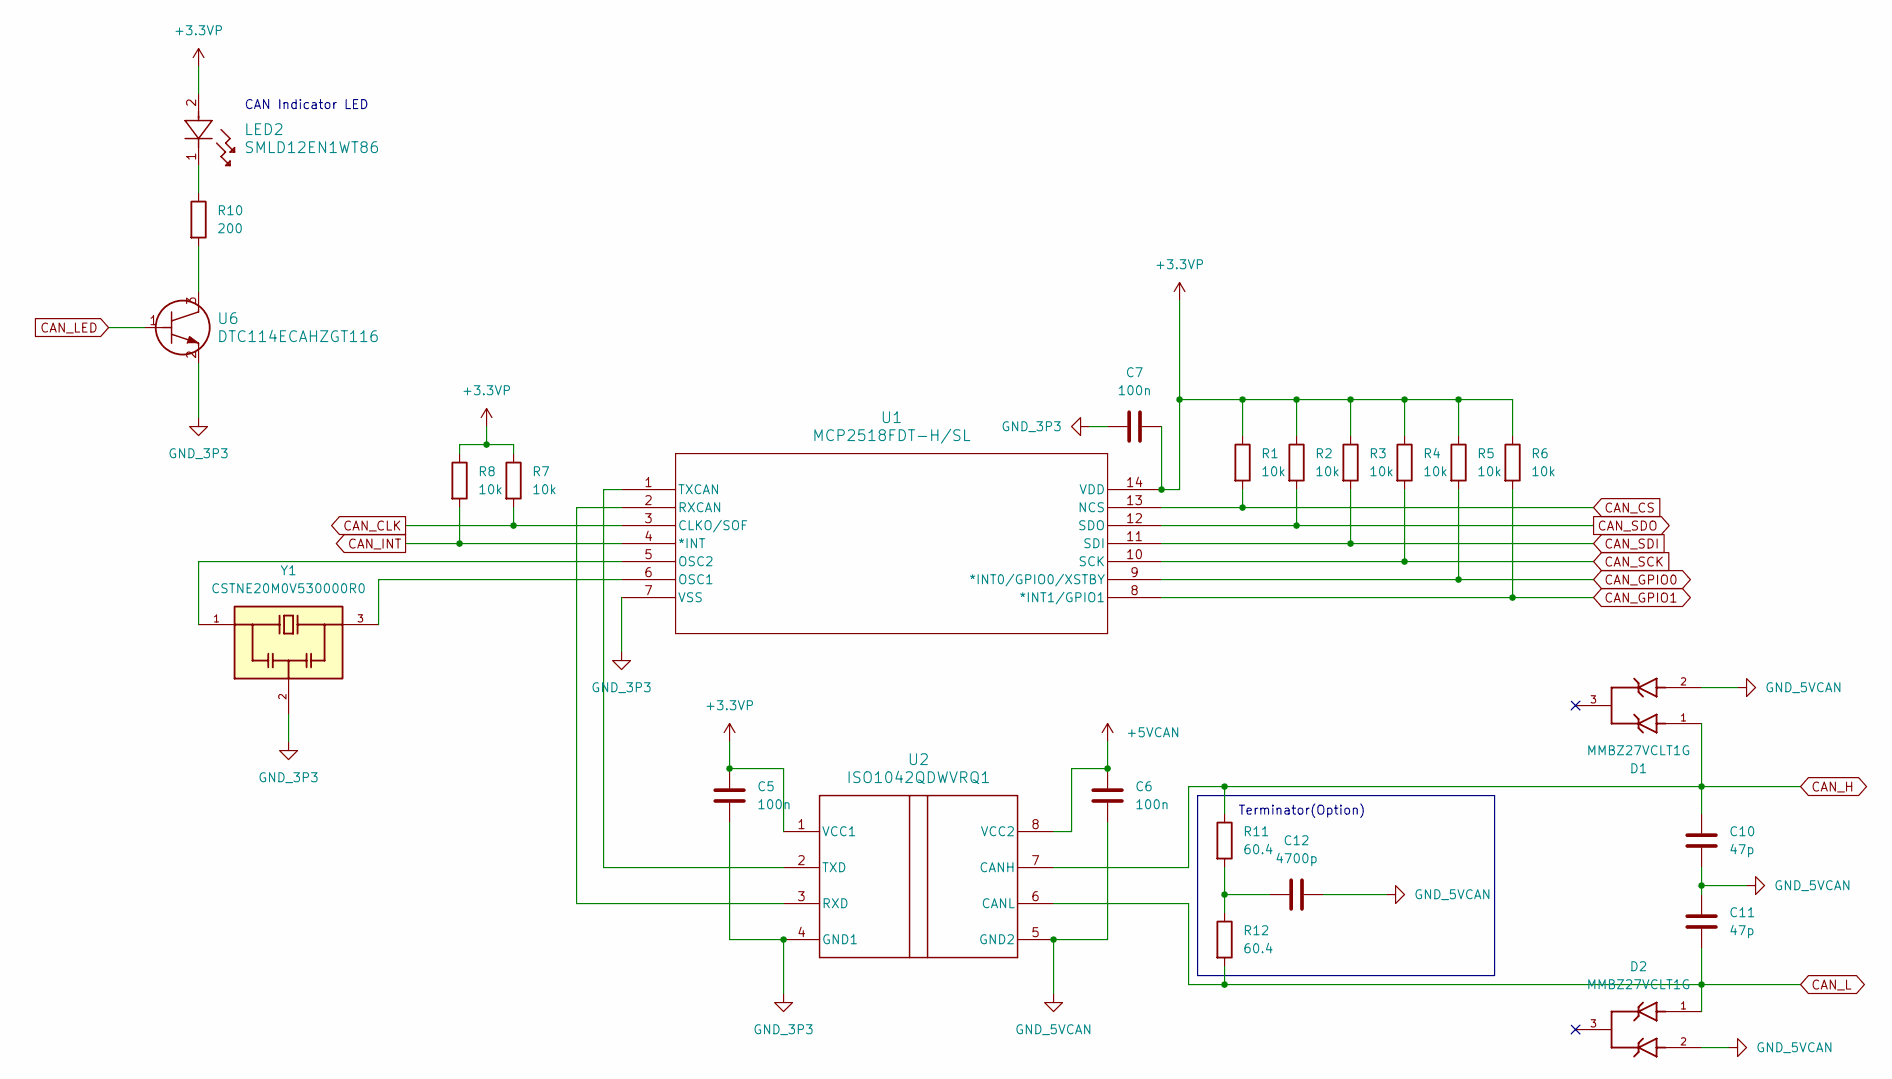
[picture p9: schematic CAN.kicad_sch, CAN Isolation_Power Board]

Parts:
C5, C6, C7: 100n; C_0603_1608Metric
C10, C11: 47p; C_0603_1608Metric
C12: 4700p; C_0603_1608Metric
D1, D2: MMBZ27VCLT1G; SOT95P237X111-3N; PARTREV 17
LED2: SMLD12EN1WT86
R1, R2, R3, R4, R5, R6, R7, R8: 10k; R_0603_1608Metric
R10: 200; R_0603_1608Metric
R11, R12: 60.4; R_Axial_DIN0207_L6.3mm_D2.5mm_P7.62mm_Horizontal
U1: MCP2518FDT-H/SL; SOIC14_150MIL_SL_MCH
U2: ISO1042QDWVRQ1; DWV0008A-IPC_A
U6: DTC114ECAHZGT116; TRANS_DTCZCAHZGT_ROM
Y1: CSTNE20M0V530000R0; OSC_CSTNE20M0V530000R0; PARTREV JGC42-8853B

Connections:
+5VCAN: C6.1, U2.8 (VCC2); also elsewhere on the board
CAN_CLK: R7.2, U1.3 (CLKO/SOF); also elsewhere on the board
CAN_CS: R1.2, U1.13 (NCS); also elsewhere on the board
CAN_GPIO0: R5.2, U1.9 (*INT0/GPIO0/XSTBY); also elsewhere on the board
CAN_GPIO1: R6.2, U1.8 (*INT1/GPIO1); also elsewhere on the board
CAN_H: C10.1, D1.1, R11.1, U2.7 (CANH); also elsewhere on the board
CAN_INT: R8.2, U1.4 (*INT); also elsewhere on the board
CAN_L: C11.2, D2.1, R12.2, U2.6 (CANL); also elsewhere on the board
CAN_LED: U6.1; also elsewhere on the board
CAN_SCK: R4.2, U1.10 (SCK); also elsewhere on the board
CAN_SDI: R3.2, U1.11 (SDI); also elsewhere on the board
CAN_SDO: R2.2, U1.12 (SDO); also elsewhere on the board
GND_5VCAN: C6.2, C10.2, C11.1, C12.2, D1.2, D2.2, U2.5 (GND2); also elsewhere on the board
unnamed: C12.1, R11.2, R12.1
unnamed: LED2.1, R10.1
unnamed: R10.2, U6.3
unnamed: U1.6 (OSC1), Y1.3
unnamed: U1.5 (OSC2), Y1.1
unnamed: U1.2 (RXCAN), U2.3 (RXD)
unnamed: U1.1 (TXCAN), U2.2 (TXD)
RF_3.3V: C5.1, C7.2, LED2.2, R1.1, R2.1, R3.1, R4.1, R5.1, R6.1, R7.1, R8.1, U1.14 (VDD), U2.1 (VCC1); also elsewhere on the board
RF_GND: C5.2, C7.1, U1.7 (VSS), U2.4 (GND1), U6.2, Y1.2; also elsewhere on the board

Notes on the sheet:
CAN Indicator LED
Terminator(Option)

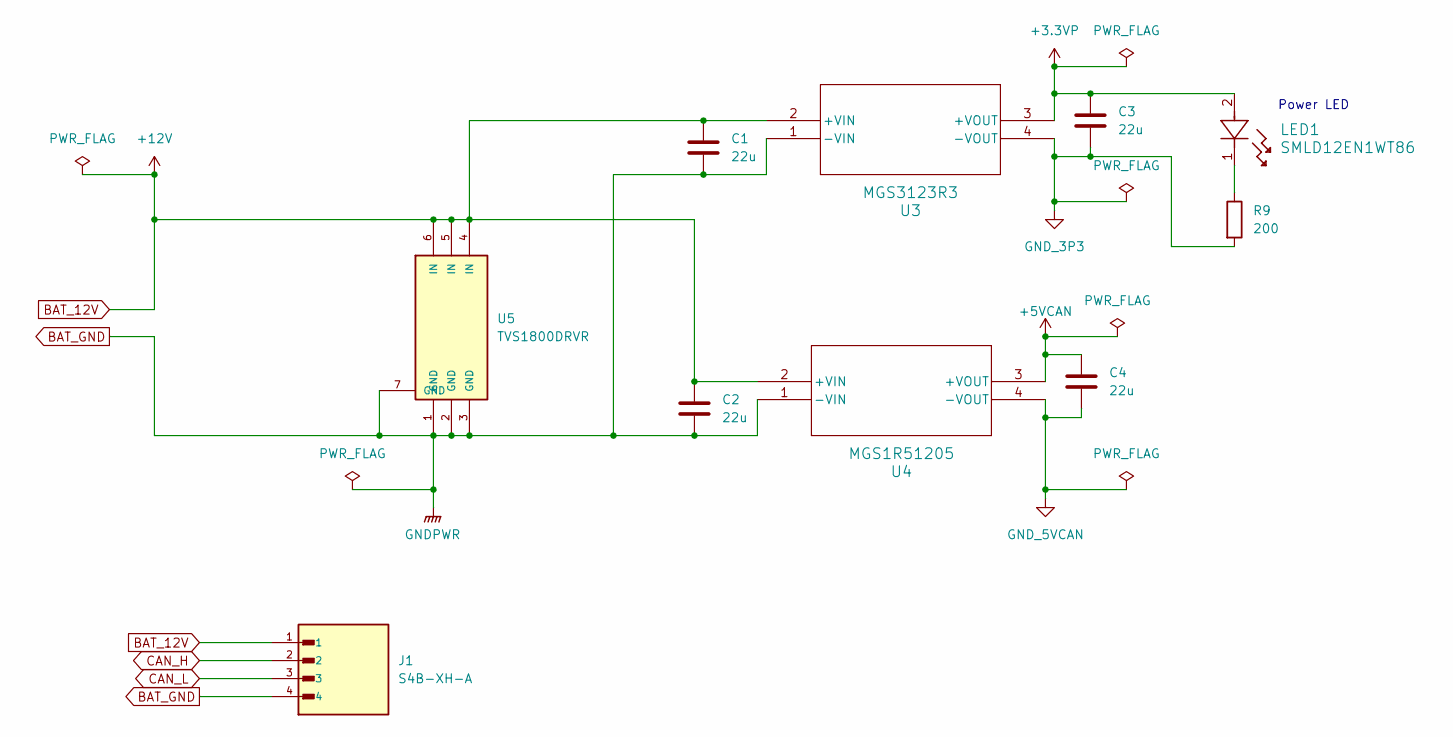
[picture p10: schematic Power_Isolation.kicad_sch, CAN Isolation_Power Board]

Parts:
C1, C2, C3, C4: 22u; C_1210_3225Metric
J1: S4B-XH-A; JST_S4B-XH-A
LED1: SMLD12EN1WT86
R9: 200; R_0603_1608Metric
U3: MGS3123R3; MGS3_COS
U4: MGS1R51205; MGS3_COS
U5: TVS1800DRVR; SON65P200X200X80-7N; PARTREV C

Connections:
+5VCAN: C4.1, U4.3 (+VOUT); also elsewhere on the board
BAT_12V: C1.1, C2.1, J1.1, U3.2 (+VIN), U4.2 (+VIN), U5.4 (IN), U5.5 (IN), U5.6 (IN)
BAT_GND: C1.2, C2.2, J1.4, U3.1 (-VIN), U4.1 (-VIN), U5.1 (GND), U5.2 (GND), U5.3 (GND), U5.7 (GND)
CAN_H: J1.2; also elsewhere on the board
CAN_L: J1.3; also elsewhere on the board
GND_5VCAN: C4.2, U4.4 (-VOUT); also elsewhere on the board
unnamed: LED1.1, R9.1
RF_3.3V: C3.1, LED1.2, U3.3 (+VOUT); also elsewhere on the board
RF_GND: C3.2, R9.2, U3.4 (-VOUT); also elsewhere on the board

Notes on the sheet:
Power LED

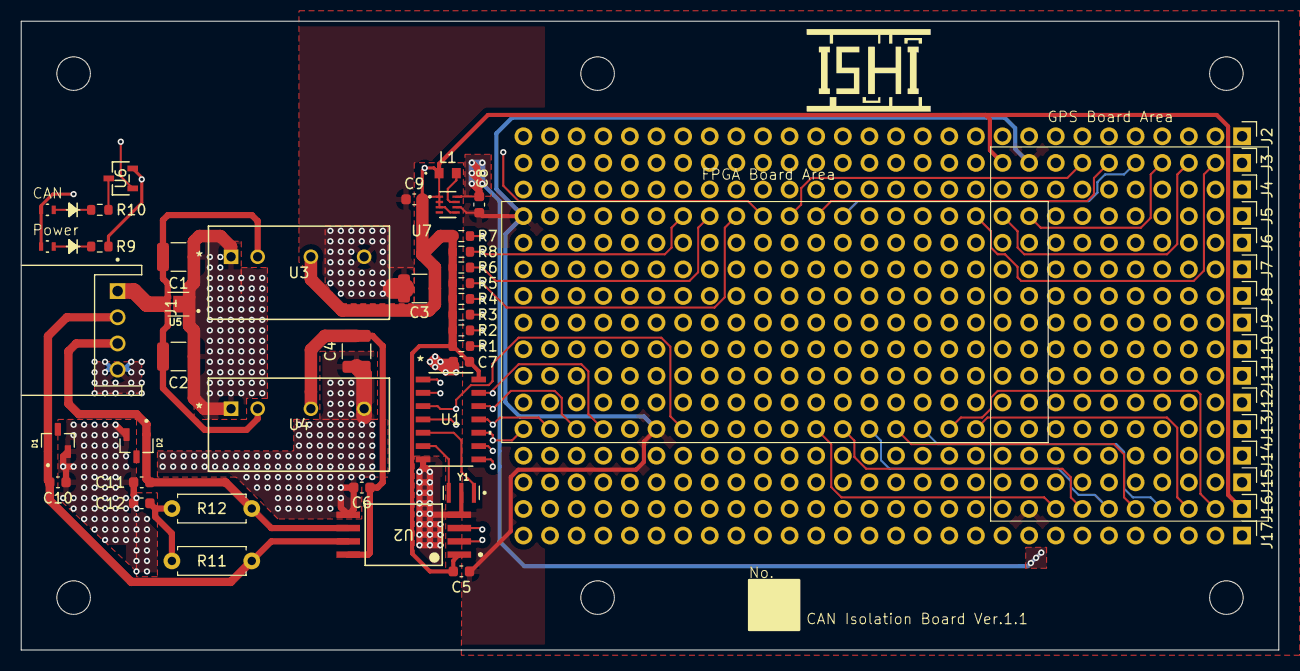
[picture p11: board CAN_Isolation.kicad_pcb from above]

Board: 4 copper layers, 120.0 x 60.0 mm, 54 parts (0 on the bottom side), 41 nets.
